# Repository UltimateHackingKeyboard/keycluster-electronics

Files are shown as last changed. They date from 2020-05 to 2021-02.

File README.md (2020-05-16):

Ultimate Hacking Keyboard key cluster module
============================================

Contained are the schematics and board layout KiCad files for the [Ultimate Hacking Keyboard](https://ultimatehackingkeyboard.com/) key cluster module.

Make sure to clone this repo with:

`git clone --recursive git@github.com:UltimateHackingKeyboard/keycluster-electronics.git`

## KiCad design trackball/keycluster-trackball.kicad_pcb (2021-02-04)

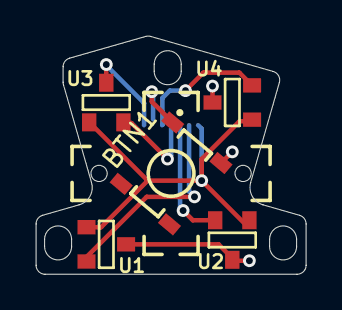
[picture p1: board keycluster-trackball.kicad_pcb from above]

Board: 2 copper layers, 15.0 x 13.2 mm, 6 parts (1 on the bottom side), 7 nets.

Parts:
BTN1: TL3315NF100Q; TL3315NFxxxQ
P8: CONN_7; FPC_Pads_7pin_0.5mm
U1, U2, U3, U4: TLE49681MXTSA1; SOT-23

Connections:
+3V3: P8.1, U1.1, U2.1, U3.1, U4.1
/TB_BTN: BTN1.1, P8.6
/TB_DOWN: P8.3, U2.2
/TB_LEFT: P8.2, U1.2
/TB_RIGHT: P8.5, U4.2
/TB_UP: P8.4, U3.2
GND: BTN1.2, P8.7, U1.3, U2.3, U3.3, U4.3

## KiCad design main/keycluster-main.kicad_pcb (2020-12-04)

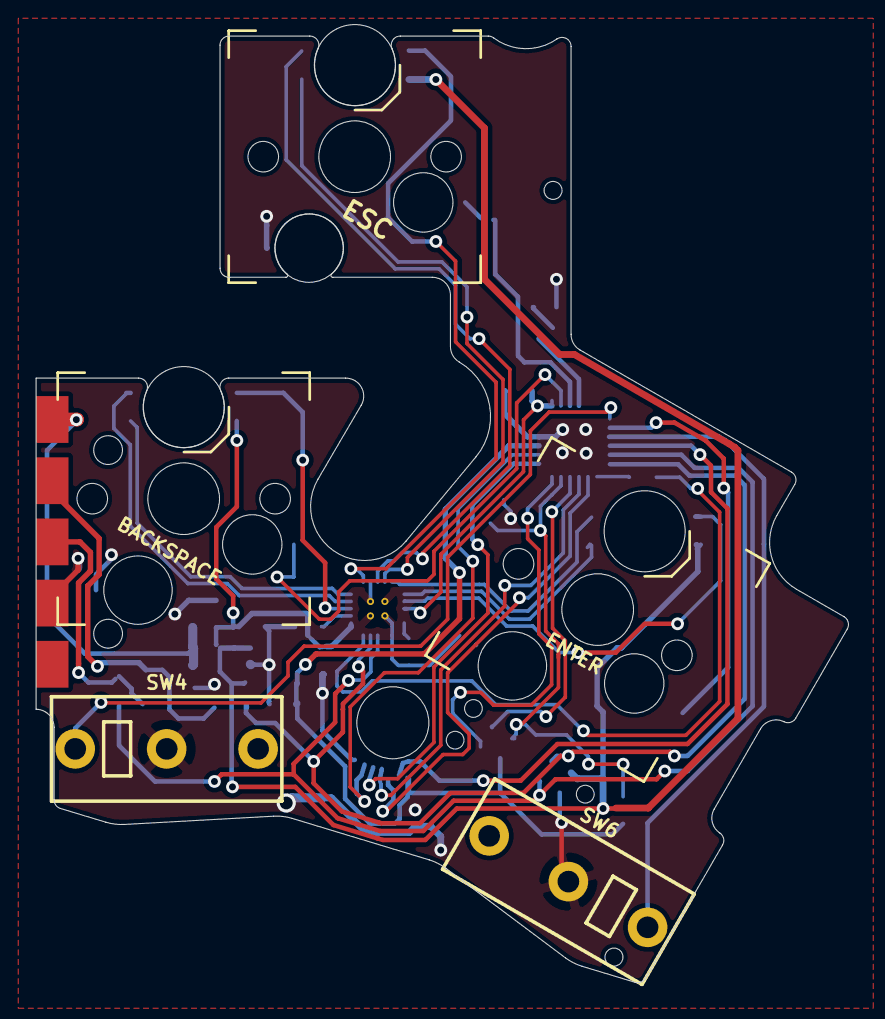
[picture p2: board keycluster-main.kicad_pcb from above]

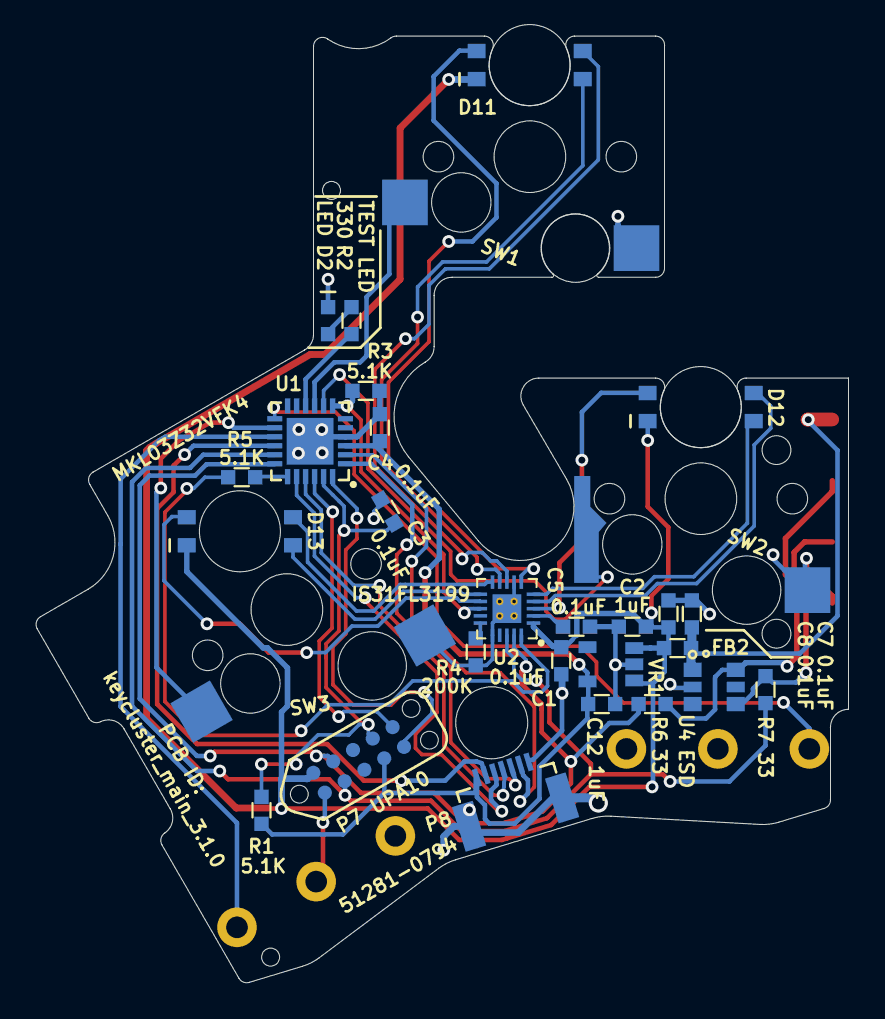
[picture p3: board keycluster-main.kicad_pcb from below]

Board: 2 copper layers, 45.1 x 52.6 mm, 35 parts (29 on the bottom side), 37 nets.

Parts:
C1, C3, C4, C5, C7, C8: 0.1uF; SM0603
C2, C12: 1uF; SM0603
D2: LED; SM0603_Diode
D11, D12, D13: RGB_LED
FB2: FERRITE_BEAD; SM0603
P2: CONN_5; UHK_Connector_TrackBall_Pcb
P7: CONN_10; Tag_Connect_2x5_Header_With_No_Legs_Parallel_Numbering
P8: CONN_7; FFC_Connector_51281-0794
R1, R3, R5: 5.1K; SM0603
R2: 330; SM0603
R4: 200K; SM0603
R6, R7: 33; SM0603
SW1, SW3: S01_Socket; S01_Hybrid_Socket
SW2: S01_Socket; S01_Hybrid_Socket_Backslash
SW4, SW6: CMI126603D08
U1: MKL03Z32VFK4; QFN-24-1EP_4x4mm_Pitch0.5mm
U2: IS31FL3199; QFN-20_EP_3x3_Pitch0.4mm
U4: ESD; SC-74-TVS
VR1: MIC5504-3.3YM5; SOT-23-5
hole: 1.0mm; hole_1.0mm
hole 2.2mm: VAL**; hole_4.0mm
hole#2: 1.0mm; hole_1.0mm

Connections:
+3V3: C4.2, C12.2, P7.7, P8.1, R1.1, U1.3, VR1.5
+5V: C1.2, C2.2, C8.2, D11.4, D12.4, D13.4, FB2.2, P7.2, U2.1, VR1.1, VR1.3
/CLK: R5.2, U1.19
/RESET: C3.2, P7.8, R1.2, U1.23
/SCL: P7.3, R7.1, U1.17, U2.18
/SCL_BOTTOM: P2.3, R7.2, U4.4
/SDA: P7.4, R6.1, U1.18, U2.19
/SDA_BOTTOM: P2.2, R6.2, U4.5
/SDB: R3.2, U1.7, U2.13
/SW1: SW1.1, U1.9
/SW2: SW2.1, U1.8
/SW3: SW3.1, U1.14
/SW4: SW4.1, U1.13
/SW5: P8.6, U1.2
/SW6: SW6.1, U1.15
/SWDCLK: P7.10, U1.22
/SWDIO: P7.9, U1.24
/TB_DOWN: P8.3, U1.20
/TB_LEFT: P8.2, U1.16
/TB_RIGHT: P8.5, U1.1
/TB_UP: P8.4, U1.21
/TEST_LED: R2.2, U1.10
/TEST_LED_R: D2.2, R2.1
/VCC_BOTTOM: C7.2, FB2.1, P2.1, U4.1
GND: C1.1, C2.1, C3.1, C4.1, C5.2, C7.1, C8.1, C12.1, D2.1, P2.4, P7.1, P8.7, R3.1, R4.1, SW1.2, SW2.2, SW3.2, SW4.2, SW6.2, U1.4, U1.25, U2.7, U2.16, U2.21, U4.2, VR1.2
unnamed: C5.1, U2.2
unnamed: D11.1, U2.8
unnamed: D11.2, U2.9
unnamed: D11.3, U2.6
unnamed: D12.1, U2.4
unnamed: D12.2, U2.5
unnamed: D12.3, U2.3
unnamed: D13.1, U2.10
unnamed: D13.2, U2.11
unnamed: D13.3, U2.12
unnamed: R4.2, U2.15
unnamed: R5.1, U2.20

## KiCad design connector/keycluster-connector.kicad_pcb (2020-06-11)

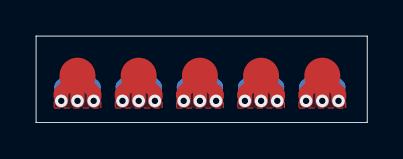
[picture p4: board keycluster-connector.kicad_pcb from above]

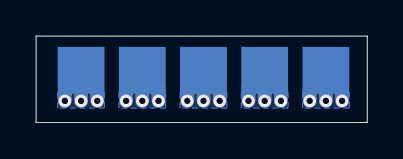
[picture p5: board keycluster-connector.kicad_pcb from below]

Board: 2 copper layers, 18.4 x 4.8 mm, 10 parts (5 on the bottom side), 5 nets.

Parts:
P11, P12, P13, P14, P15: CONN_1; UHK_Connector_Right_Outer_Pad
P21, P22, P23, P24, P25: CONN_1; UHK_Connector_Right_Inner_Pad

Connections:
unnamed: P11.1, P21.1
unnamed: P12.1, P22.1
unnamed: P13.1, P23.1
unnamed: P14.1, P24.1
unnamed: P15.1, P25.1

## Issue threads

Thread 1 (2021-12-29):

full horizontal row support (missing 2 keys only)

G2G2G2G, 2021-12-29:
My left hand uses next tier of keys in qwerty.. (because the right hand is mostly on the mouse, my highly evolved left hand has learned more of the keyboard)
Y
H
N
You currently have the "6" key which is part of this layer, but cut it off at T, G and B..
Currently the only left hand module adds 3 keys, I am thinking what if you were to add more modular keys for people like me?
Something like:
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
adding the key in the "7" place isn't fully necessary, but H and Y are

Thanks
(sorry if wrong section, this seemed to be the most applicable)

mondalaci, 2021-12-30:
Hi there! We don't plan to make such a module, but we'll release a development kit, so non-official modules, such as the one you're suggesting, will be possible to be made.

Closed 2021-12-30.

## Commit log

2019-05-13 PCB added with mechanical layers.
    [keycluster.kicad_pcb]
2019-05-21 Vertical and trackball pcb.
    [keycluster.kicad_pcb, keycluster_trackball_pcb.kicad_pcb, keycluster_vertical_pcb.kicad_pcb]
2019-05-27 Add version numbers on the silk screen.
    [keycluster.kicad_pcb, keycluster_trackball_pcb.kicad_pcb]
2019-06-06 Keycluster project files added.
    [keycluster.kicad_pcb, keycluster.sch]
2019-06-06 Keycluster sch. page settings.
    [keycluster.sch]
2019-06-06 Button positions changed on uC.
    [keycluster.sch]
2019-06-06 Wiring on main pcb.
    [keycluster.kicad_pcb]
2019-06-11 Reed removed. Legless tag connector.
    [keycluster.sch]
2019-06-20 Wiring on main pcb and 7pin FFC added.
    [keycluster.kicad_pcb, keycluster.sch]
2019-06-25 First final version pcb of main board.
    [keycluster.kicad_pcb]
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2019-06-25 Modified varsion number on main board. 0.1.0 -> 1.0.0
    [keycluster.kicad_pcb, keycluster.sch]
2019-06-25 Trackball project added. First final version of this board.
    [keycluster_trackball.kicad_pcb, keycluster_trackball.sch, keycluster_trackball_pcb.kicad_pcb]
2019-06-25 Designators layer changed. tslk -> bslk
    [keycluster_trackball.kicad_pcb]
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2019-07-02 Add updated vertical PCB and delete the old, incorrect one.
    [connector.kicad_pcb, connector.sch, keycluster_vertical_pcb.kicad_pcb]
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2019-07-03 Rename the Trackball directory to lowercase trackball.
    [keycluster_trackball.kicad_pcb, keycluster_trackball.sch]
2019-07-03 Rename keycluster_trackball.* to trackball.* and fix trackball schematics library path.
    [trackball.kicad_pcb, trackball.sch]
2019-07-03 Make board outline continuously connected.
    [trackball.kicad_pcb]
2019-07-03 Update key cluster contour.
    [keycluster.kicad_pcb]
2019-07-03 Update soft keepout areas.
    [keycluster.kicad_pcb]
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2019-07-07 Show silk screen values.
    [keycluster.kicad_pcb]
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2019-07-07 Move main board to the new main directory.
    [keycluster.kicad_pcb, keycluster.sch]
2019-07-07 Rename keycluster.* files to main.*
    [main.kicad_pcb, main.sch]
2019-07-07 Spruce up the silk screen.
    [trackball.kicad_pcb]
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2019-07-17 Change hall sensor on trackball.
    [trackball.kicad_pcb, trackball.sch]
2019-07-17 Change UPA header pinout.
    [main.kicad_pcb, main.sch]
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2019-08-06 Update contour based on CAD.
    [main.kicad_pcb]
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2019-08-06 Update keepout areas based on CAD.
    [main.kicad_pcb]
2019-08-06 Fix outline to be continuous.
    [main.kicad_pcb]
2019-08-06 Remove inner edge layer artifacts and refill ground.
    [main.kicad_pcb]
2019-08-06 Spruce up silk screen.
    [main.kicad_pcb]
2019-08-06 Assign the same value to microswitches so that they'll be featured in a single BOM line.
    [main.kicad_pcb, main.sch]
2019-08-06 Assign the same value to RGB LEDs.
    [main.kicad_pcb, main.sch]
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2019-08-06 Feature RGB LEDs on the correct side.
    [main.kicad_pcb]
2019-08-07 Update sockets and put them on the back side.
    [main.kicad_pcb]
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2019-08-09 Update the FFC connector of the main board.
    [main.kicad_pcb]
2019-08-09 Fix the module library path and update the FFC connector of the trackball board.
    [trackball.kicad_pcb]
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2019-08-15 Inrease contour width (custom edge.cuts clearance).
    [trackball.kicad_pcb]
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2019-08-16 Make pogo pin through hole and make logo virtual.
    [main.kicad_pcb]
2019-08-16 Make the values of RGB LEDs "RGB LED".
    [main.kicad_pcb]
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2019-08-21 Fix outline.
    [trackball.kicad_pcb]
2019-08-21 Resolve 1 DRC error. 2 to go.
    [trackball.kicad_pcb]
2019-08-21 Move top edge upward by 0.3 mm. Resolve DRC issues.
    [trackball.kicad_pcb]
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2019-08-21 Fix the angle of C5.
    [trackball.kicad_pcb]
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2019-08-21 Leave more space at the bottom of the board.
    [trackball.kicad_pcb]
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2019-09-25 Fix schematic dependencies, so every component renders properly.
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2019-10-27 Update pogo pin module and reroute board around it.
    [main.kicad_pcb]
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2020-01-11 Update schematic and board design with new uC. Remove LED driver.
    [main.kicad_pcb, main.sch]
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2020-01-24 Make the test LED and its resistor virtual.
    [main.kicad_pcb]
2020-02-07 Redesign panel with TLE4964.
    [trackball.kicad_pcb, trackball.sch]
2020-02-07 Improve the silk screen of the main board.
    [main.kicad_pcb]
2020-02-07 Bump the version number of both boards to 2.0.0
    [main.kicad_pcb, main.sch, trackball.kicad_pcb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]
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2020-03-14 Update contour to rigid-flex.
    [trackball.kicad_pcb]
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2020-03-14 Fix switch position and orientation.
    [trackball.kicad_pcb]
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2020-03-14 Display PCB ID on the back of the PCB.
    [trackball.kicad_pcb]
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2020-04-05 Disconnect the bottom pin of the pogo pin connector.
    [main.kicad_pcb, main.sch]
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2020-05-17 Change parts from 4.7K to 5.1K and from 47 ohm to 33 ohm.
    [main.kicad_pcb, main.sch]
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2020-05-21 Clone trackpoint FPC here. To be modified soon.
    [keycluster-fpc.kicad_pcb]
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2020-05-21 Add missing FPC features and close the outline.
    [keycluster-fpc.kicad_pcb]
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2020-06-06 Move parts away from SW_MRK1 to ease hand its soldering.
    [main.kicad_pcb]
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2020-06-06 Move components away from SW_MLK1 for easier solderability.
    [main.kicad_pcb]
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2020-06-19 Update stiffener marking.
    [keycluster-fpc.kicad_pcb]
2020-06-19 Update stiffener marker position.
    [keycluster-fpc.kicad_pcb]
2020-06-19 Increase key cluster silk screen text and shorten it to be manufacturable.
    [keycluster-fpc.kicad_pcb]
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2020-08-03 Update QFN-32_EP_5x5_Pitch0.5mm.kicad_mod to fix center pad paste.
    [keycluster-main.kicad_pcb]
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2020-08-04 Set up clearance so that part of the logo is not covered by the soldermask around the nearby hole.
    [keycluster-main.kicad_pcb]
2020-08-04 Update sockets to not feature silk screen between their holes.
    [keycluster-main.kicad_pcb]
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2020-09-22 Move the FFC connector by about 0.8 mm away from the edge of the main board.
    [keycluster-main.kicad_pcb]
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2020-09-25 Add FPC tracks and bump version to 2.0.0
    [keycluster-fpc.kicad_pcb]
2020-09-25 Reposition FPC solder pads and bump version to 2.3.0
    [keycluster-trackball.kicad_pcb, keycluster-trackball.sch]
2020-09-25 Add guiding silk screen lines to ease FPC soldering.
    [keycluster-trackball.kicad_pcb]
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2020-09-30 Fix hall sensor part name.
    [keycluster-trackball.sch]
2020-09-30 Replace the TL3315NF250Q module with TL3315NFxxxQ and use TL3315NF100Q as the part value to describe the actual part name.
    [keycluster-trackball.kicad_pcb, keycluster-trackball.sch]
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2020-10-27 Reallocate control pins on schematic and routing on PCB.
    [keycluster-main.kicad_pcb, keycluster-main.sch]
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2020-10-28 Fix LED driver supply connect.
    [keycluster-main.kicad_pcb]
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2020-10-29 Update the resistor values around the LED driver.
    [keycluster-main.sch]
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2020-10-29 Rename the test LED reference designator to D2.
    [keycluster-main.kicad_pcb, keycluster-main.sch]
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2021-02-04 Set the microswitch of the trackball board to SMD instead of through-hole.
    [keycluster-trackball.kicad_pcb]
